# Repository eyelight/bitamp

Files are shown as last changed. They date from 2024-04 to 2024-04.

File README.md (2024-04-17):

# Bitamp

The Bitamp is a guitar foot pedal intended to pass along the signal of a Bitcaster guitar, while switching on/off the delivery of 5v to a [Bitaxe](https://github.com/skot/bitaxe) embedded in the guitar body.

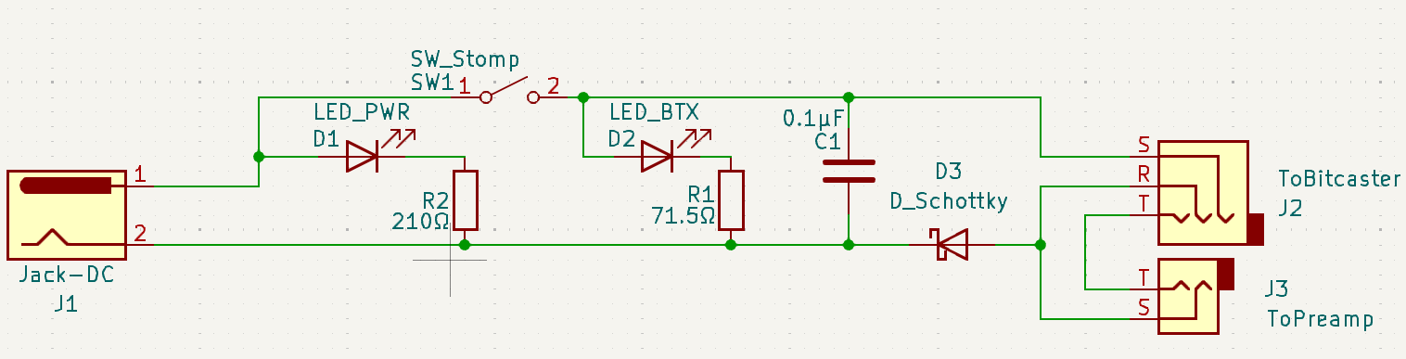
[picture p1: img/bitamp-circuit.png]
*current circuit diagram found in the Kicad project in this repo*

On the other end of the Bitamp should be a Bitcaster guitar. The Bitcaster is equipped with a TRS stereo jack instead of the typical TS mono jack, and the Bitamp expects a TRS stereo cable with the following pin assignments:

| Pin | Function |
| :-- | :-- |
| Tip | + Guitar pickup |
| Ring | common ground |
| Sleeve | +5v from power barrel jack |

The Bitamp's output passes along the guitar signal through a standard TS guitar cable, with the following pin assignments:

| Pin | Function |
| :-- | :-- |
| Tip | + Guitar pickup |
| Sleeve | - ground |

The Bitamp foot switch will toggle the delivery of 15 watts of 5V DC through the Sleeve (+) and Ring (-) of of the TRS jack. 

When the foot switch is toggled on, a warm white LED will illuminate and back light a Bitcoin logo cut into the pedal's body. 

The Bitamp also has a blue power indicator LED.

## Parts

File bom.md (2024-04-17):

## Bill of Materials

| Qty | Mfgr | Part (Datasheet) | Part (Purchase) | Description |
| :--: | :--: | :--: | :--: | :-- |
| 1 | Electroswitch | [6611](https://www.electro-nc.com/sites/electro-nc/files/6600.pdf) | [451-1201-ND](https://www.digikey.com/en/products/detail/electroswitch/6611/2679595) | Stomp switch push on/off SPST 10A |
| 1 | Switchcraft | [111X](https://www.switchcraft.com/assets/1/24/110x-m110x_series_cd.pdf?5406) | [SC2830-ND](https://www.digikey.com/en/products/detail/switchcraft-inc/111X/1288958) | Panel mount TS mono jack 6.35mm |
| 1 | Amphenol | [ACJS-MN-3](https://www.amphenolaudio.com/wp-content/uploads/2015/07/55010660000110_acjs-mhdcm.pdf) | [889-ACJS-MN-3-ND](https://www.digikey.com/en/products/detail/amphenol-sine-systems-corp/ACJS-MN-3/10443644) | Panel mount TRS stereo jack 6.35mm |
| 1 | Tensility International Corp | [54-00063](http://tensility.com/pdffiles/54-00063.pdf) | [839-1291-ND](https://www.digikey.com/en/products/detail/tensility-international-corp/54-00063/6206244) | Power jack 2.1x5.5mm |
| 1 | McMaster-Carr | 75895K31 | [75895K31](https://www.mcmaster.com/75895K31/) | Aluminum enclosure 4.5" x 2.625" x 1.25" |
| 1 | Kemet | [C410C104K3R5TA7200](https://content.kemet.com/datasheets/KEM_C1041_AXIMAX_X7R.pdf) | [399-C410C104K3R5TA7200CT-ND](https://www.digikey.com/en/products/detail/kemet/C410C104K3R5TA7200/14681403) | C1: 0.1µF ceramic capacitor |
| 1 | Wurth Elektronik | [151033BS03000](https://www.we-online.com/katalog/datasheet/151033BS03000.pdf) | [732-5011-ND](https://www.digikey.com/en/products/detail/w%C3%BCrth-elektronik/151033BS03000/4489997) | D1: 3mm 2.8Vf 20mA 3800mcd blue LED, power indicator |
| 1 | CreeLED | [JK3030AWT-P-B30EA0000-N0000001](https://downloads.cree-led.com/files/ds/j/JSeries-3030.pdf) | [2138-JK3030AWT-P-B30EA0000-N0000001CT-ND](https://www.digikey.com/en/products/detail/creeled-inc/JK3030AWT-P-B30EA0000-N0000001/8020355) | D2: warm white LED, active when Bitaxe/Bitcaster is powered |
| 1 | Vishay | [MRS25000C2100FCT00](https://www.vishay.com/docs/28724/mrs16m25.pdf) | [BC4049CT-ND](https://www.digikey.com/en/products/detail/vishay-beyschlag-draloric-bc-components/MRS25000C2100FCT00/5064191) | R1: 210 ohm 0.6w 1% axial resistor for power LED |
| 1 | Vishay | [MRS25000C7159FCT00](https://www.vishay.com/docs/28724/mrs16m25.pdf) | [56-MRS25000C7159FCT00CT-ND](https://www.digikey.com/en/products/detail/vishay-beyschlag-draloric-bc-components/MRS25000C7159FCT00/5064631) | R2: 71.5 ohm 0.6w 1% axial resistor for BTC LED |
| 1 | Vishay | [SL43-M3/57T](https://www.vishay.com/docs/88742/sl42.pdf) | [SL43-M3/57TGICT-ND](https://www.digikey.com/en/products/detail/vishay-general-semiconductor-diodes-division/SL43-M3-57T/4873689) | Shottkey diode for isolating the guitar signal |

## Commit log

2024-03-29 ignore kicad backups
2024-03-29 initial kicad
    [bitamp.kicad_pcb, bitamp.kicad_sch]
2024-04-17 add BOM
2024-04-17 add circuit image
2024-04-17 update kicad files
    [bitamp.kicad_sch]
